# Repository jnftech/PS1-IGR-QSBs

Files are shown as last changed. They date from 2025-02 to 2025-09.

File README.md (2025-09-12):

## Playstation 1 In-Game Reset (IGR)
### QSBs for One-wire Controller-PCB installs
<br/>
<br/>

These boards are variations on [PyroESP's](https://github.com/pyroesp) Playstation 1 Reset Mod project.

The original project and code can be found at https://github.com/pyroesp/PlayStation-1-Reset-Mod

To simplify the goal of this project: When installed into a Playstation 1 system, it facilitates a reset of the system using a button combination on controller 1, by tapping into the controller signals and toggling the system reset line. This is useful for those that have ODEs installed, as you can reset back to the menu of the ODE from the controller instead of getting up to hold the reset button down.

Originally I had posted a variation that was more or less a shrink of their original PCB (which used a SOIC package for the microcontroller), but using the TSSOP version instead, to get the board as small as it could be for S&Gs and more of a "hardmode" install. This version of the project (while deprecated, unless you REALLY need to avoid installing to the controller PCB) is still hosted in the repository.

A while back (2022? Yes it has taken me that long to publish the final versions here) a member of the [Consolemods.org](https://www.consolemods.org) discord observed a variation on OSHpark that installed to the back of the controller PCB behind the player 1 port. However the project was not laid out correctly, thus the wrong (higher) voltage was applied to the microcontroller. This style of board is a "Quick Solder Board" (QSB), where the board is designed to sit on top of another PCB and solder directly to signal points (versus running a wire for each signal). Such a solution allows for a "one-wire" install of this project. All but one of the signals needed are available from the solder points of the controller ports themselves. The only wire that must be run is for the reset signal.
While these controller-PCB-mounted solutions were not uncommon at the time, the project on OSHpark appeared to be the only published gerbers for folks that prefer to fabricate their own PCBs.
I decided to revisit the project to produce a correctly-wired version, using my own consoles for measurement. Some earlier versions of the gerbers were posted to the discord for members to use. This respository has three variations depending on your soldering preferences.
  
Code, details of the solution, original PCB design, and instructions for programming and installation are available at [pyroesp's Github](https://github.com/pyroesp). Programming-ready hex file in the [releases section](https://github.com/pyroesp/PlayStation-1-Reset-Mod/releases)

</br></br></br>

### Controller-port (Port 1) install, SOIC Package (Normal difficulty) [(OSHpark)](https://oshpark.com/shared_projects/fwJTyytg)

<p align="center">
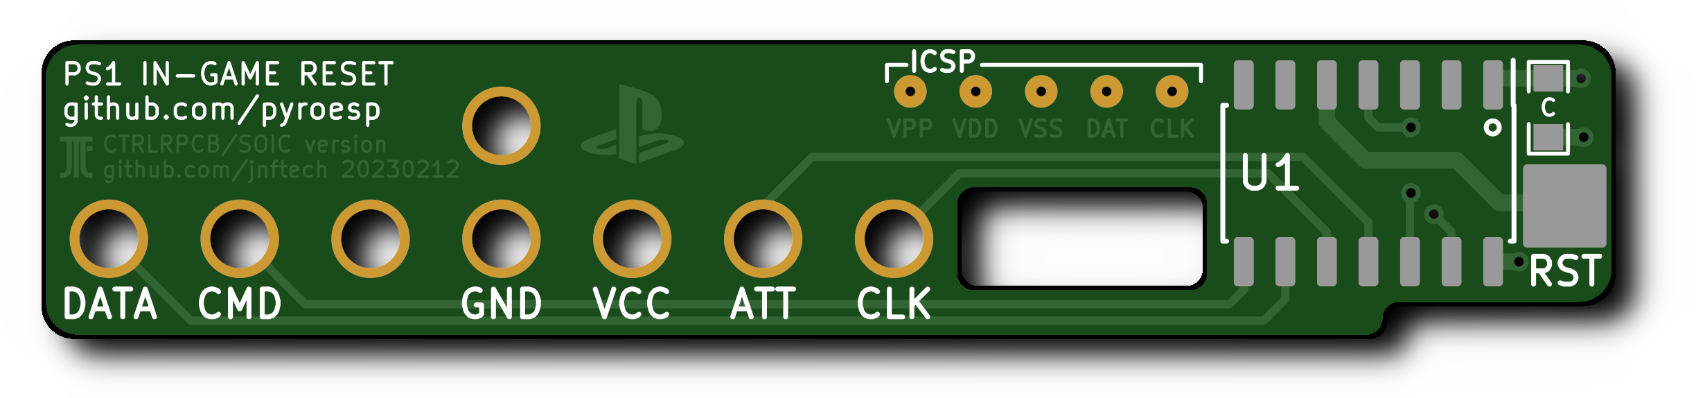
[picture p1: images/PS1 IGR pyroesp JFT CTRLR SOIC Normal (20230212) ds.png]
  
</p>
This variant more or less aimed to substitute the faulty one on OSHpark. Installs over the solder points for controller port 1 and uses the SOIC package of the microcontroller (MCU). This should be fairly easy to assemble for anyone with decent soldering skills.

</br></br>

### Controller-port (Port 1) install, TSSOP Package (Hard difficulty) [(OSHpark)](https://oshpark.com/shared_projects/G71d1amG)

<p align="center">
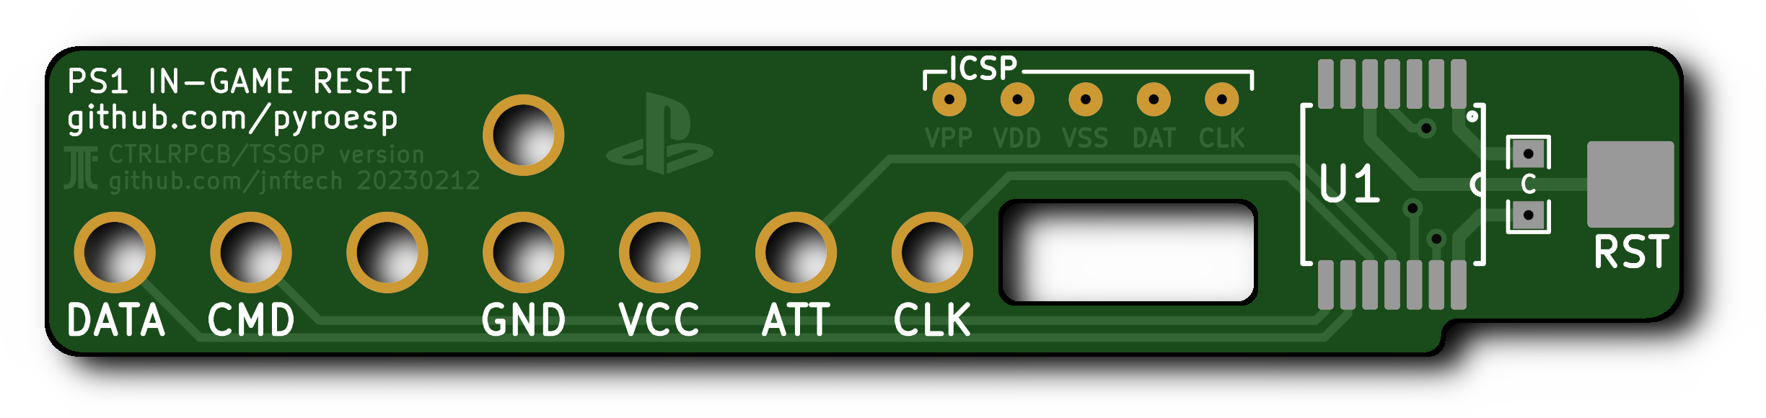
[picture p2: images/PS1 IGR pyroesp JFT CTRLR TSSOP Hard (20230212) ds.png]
  
</p>
This is almost identical to the above variant, and installs the exact same way. The only difference is the use of the TSSOP package for the MCU. This requires slightly tighter soldering skills.

</br></br>

### Controller-ribbon connector (Center of controller PCB) install, UQFN Package (Ultrahard difficulty) [(OSHpark)](https://oshpark.com/shared_projects/B2ZQAGCg)

<p align="center">
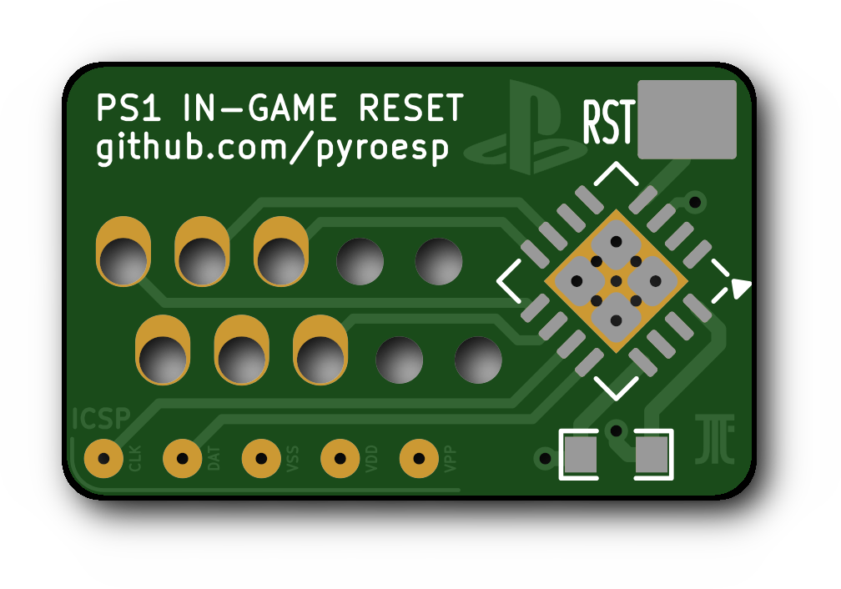
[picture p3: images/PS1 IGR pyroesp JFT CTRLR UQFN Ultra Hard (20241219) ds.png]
  
</p>
Staying in the same spirit as my original visit to the project, this board aims to be as small is it can be. I realized that another spot on the controller PCB contained all the same signals as the controller port: The connector for the ribbon cable that connects the controller assembly to the main system board. This PCB installs to the back of that connector instead of the controller port. Continuing with that same spirit, I figured go all out and use the UQFN package of the MCU - which is the smallest package it comes in. However this means this board is significantly more difficult to assemble by hand. Not impossible - I hand assembled the one installed in my main console - but takes very good soldering skills and tools. I imagine this is the smallest "one-wire" install of this solution available. All that said, the actual installation of the board into the console should not be much more difficult than the other two options.

</br></br>

### PSone install, Flex PCB, UQFN Package (Insane difficulty) BETA

<p align="center">
  
</p>
Info coming soon!
(Quick note for anyone that wants to try this one before I get around to filling in more details - this is intended to be a flex PCB to keep it as thin as possible (flex is 0.10mm - 0.12mm) and fit under the bottom RF shield. Put kapton tape over it after installation to keep it from touching the RF shield. I have tested this install on a PSone and it works as intended. Normal PCBs are likely too thick, though I have not tried this myself. Perhaps if the RF shield is cut or omitted a regular PCB would fit. i would still go as thin as possible, for example the 0.8mm on Oshpark. Though until I provide more detailed instructions, you will have to find the reset line on the PSone yourself, or look around online. I found a good spot from the PSone service manual.)

</br></br></br></br>

### BOM:

Only two components are needed:

**U1**<br/> Depending on which board you which to assemble, the part number for the MCU will differ slightly (only the last two characters of the part number matter in this case)
- SOIC: Microchip PIC16F18325-I/SL. [Digikey](https://www.digikey.com/en/products/detail/microchip-technology/PIC16F18325-I-SL/5323625)
- TSSOP: Microchip PIC16F18325-I/ST. [Digikey](https://www.digikey.com/en/products/detail/microchip-technology/PIC16F18325-I-ST/5323626)
- UQFN: Microchip PIC16F18325-I/JQ. [Digikey](https://www.digikey.com/en/products/detail/microchip-technology/PIC16F18325-I-JQ/5639473)

**C1**:<br/>You really don't need to be picky about this part. Any 100nf to 1000nf/1uf 0603-sized Ceramic capacitor rated at 16v or above will work. <br />
    Examples:<br />
        [Samsung CL10B104KB8NNNL](https://www.digikey.com/en/products/detail/samsung-electro-mechanics/CL10B104KB8NNNL/3894274)<br />
        [Murata GCJ188R71E104KA12D](https://www.digikey.com/en/products/detail/murata-electronics/GCJ188R71E104KA12D/7363221)

### Installation Notes:
- To completely remove the chance of shorts between the IGR board and any shielding it may come in contact with, place a piece of electrical tape over the board once installed, OR place electrical tape over the sheilding area it may come in contact with. I will add a photo of this at some point.

### Fabrication Notes:
- These boards benefit from being as thin as possible, due to being positioned between the controller PCB and the metal shielding between it and the rest of the casing. The default 1.6mm PCB thinckness may be a little tight, so it's recommended to go with 0.8mm thickness. If using OSHpark, an 0.8mm width option is available at checkout. Other fabs should have a similar thickness option, even thinner in some cases.
- The text in the bottom copper layer *may* cause some fabs to complain about the size of the text. OSHpark doesnt have an issue (they seem to fab whatever you throw at them, regardless if it comes out well in the final product), but I have experienced cases in the past where JLCPCB will remove any text from the board that they deem too small.
- There are other variants of the MCU you can use, depending on whether you have trouble sourcing the above (I did when I built my prototypes) but they may be a few cents more expensive as they have extra features or tolerances. In this project, they will all function identically:
  - The "I/" in the part number can be swapped with the "E/" variant. The latter is just "Extended Tempurature range"
  - This project uses the PIC16F18325 MCU, however the the PIC16F18**326** can also be used. It's the exact same MCU with a little bit more memory and storage. Same HEX file can be used to program either. The board I installed in my main console uses the PIC16F18326-E/JQ part. While the size of the code is fairly small, the next MCU down in the list (324) CANNOT be used as it lacks the dual SPI capability of the 325 and 326 (which this project requires).
- You will of course need a programmer to flash the code to the microcontroller, such as a PICkit3. This can be done in several ways:
  - The ICSP pads on board by soldering some temporary wiring to connect it to the programmer.
  - The ICSP pads by using a 2mm pitch pogo-pin PCB clamp such as this one on [Aliexpress](https://www.aliexpress.com/i/3256806664884457.html)
  - An alternative would be a DIP socket adapter ([an example of such on Aliexpress](https://www.aliexpress.com/item/32868905130.html)) to house the chip for programming before it is soldered to the board.

### Other Notes:
- These have not been designed with the PSone in mind, and are only tested on the original "phat" models. While the PSones have no good ODE option yet (where this mod is most useful), I have a variation in beta that I will be testing in the next few weeks.

### Tools used for this project:
- Tracespace View (SVG conversions of gerbers for the above images) https://tracespace.io/view/
- KiCad 8.0.6 https://www.kicad.org/
- GIMP for some of the image edits.
- Inkscape for some vector image edits.

### To-do
- Post more detailed installation instructions
- Post or link to reset line points for various motherboard revisions.

### License:
This derivative work maintains the same source license as the original board and project:  
Attribution-ShareAlike 4.0 International. See license file for more info

<br/><br/><br/><br/>
<p align="center">
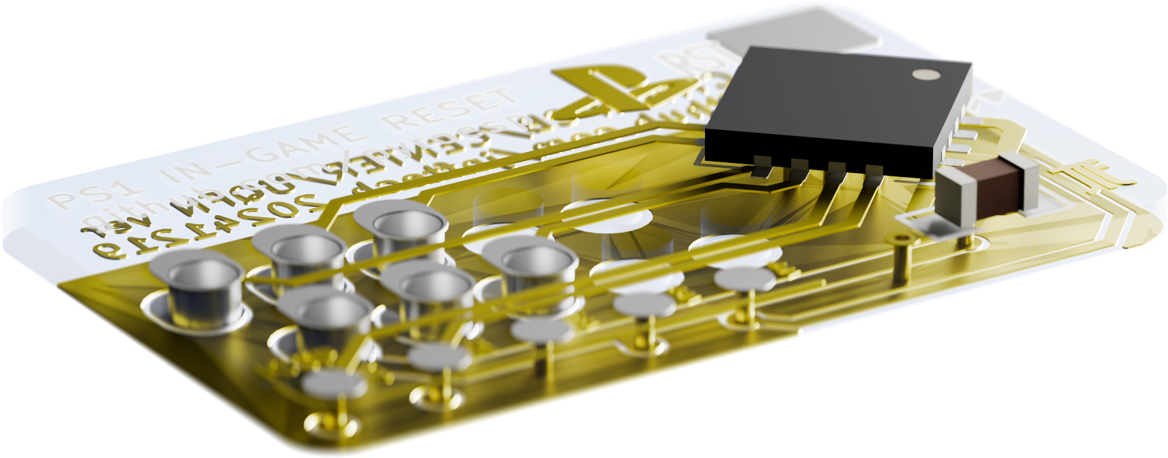
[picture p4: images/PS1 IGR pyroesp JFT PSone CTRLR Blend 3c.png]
  
</p><p align="center">
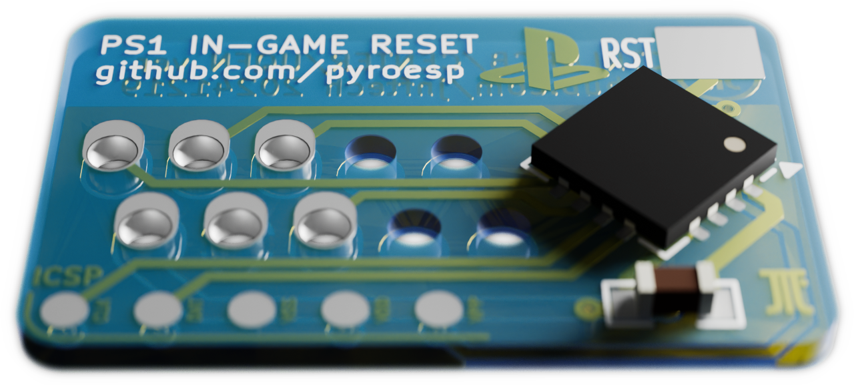
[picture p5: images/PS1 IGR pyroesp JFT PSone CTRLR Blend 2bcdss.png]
  
</p>
<br/><br/>

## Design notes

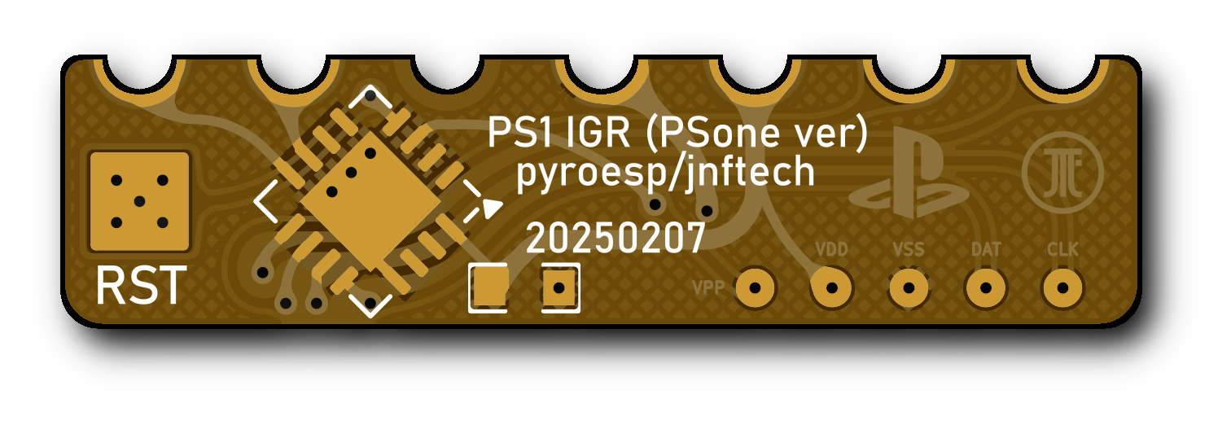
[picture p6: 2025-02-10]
images/PS1 IGR pyroesp JFT PSone UQFN (20250207) top flex ds.png

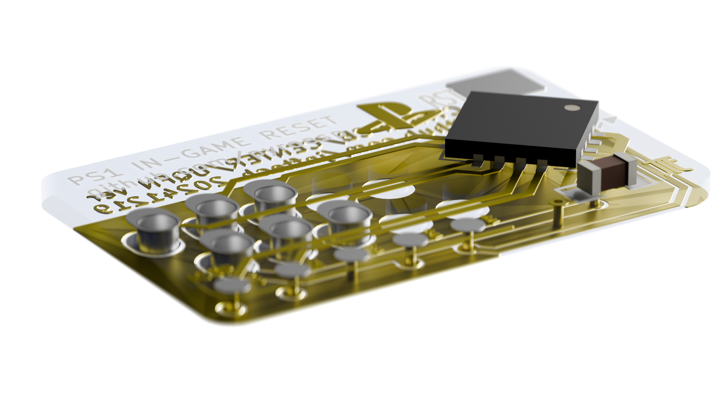
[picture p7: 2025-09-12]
images/PS1 IGR pyroesp JFT PSone CTRLR Blend 3.png

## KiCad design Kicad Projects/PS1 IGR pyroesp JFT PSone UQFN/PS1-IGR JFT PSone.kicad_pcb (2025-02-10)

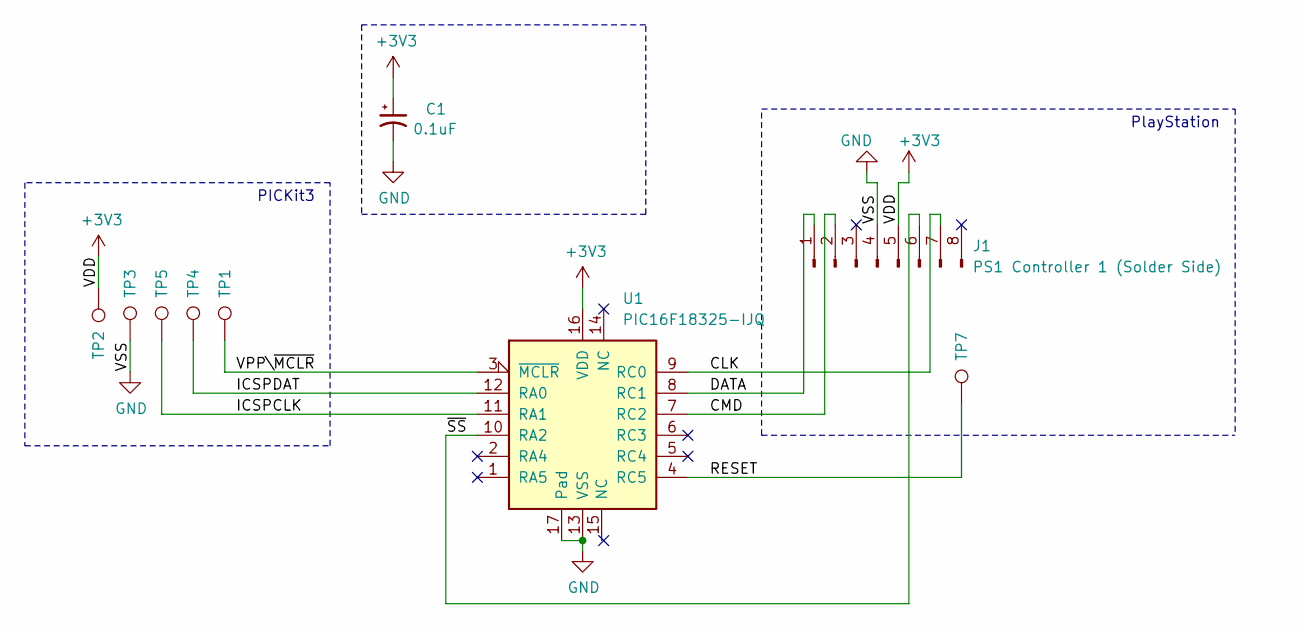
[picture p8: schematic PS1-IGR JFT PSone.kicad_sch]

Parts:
C1: 0.1uF; R_0603_0.8mm
J1: PS1 Controller 1 (Solder Side); PS1ControllerPort_SolderSide_1gnd0hv
TP1: VPP; TestPoint_Pad_NoSilk_D1.0mm
TP2: VDD; TestPoint_Pad_NoSilk_D1.0mm
TP3: VSS; TestPoint_Pad_NoSilk_D1.0mm
TP4: DAT; TestPoint_Pad_NoSilk_D1.0mm
TP5: CLK; TestPoint_Pad_NoSilk_D1.0mm
TP7: RST; Wirepad-2.54mm
U1: PIC16F18325-IJQ; UQFN-16-1EP_4x4mm_P0.65mm_EP2.6x2.6mm

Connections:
+3V3: C1.1, J1.5, TP2.1, U1.16 (VDD)
/CLK: J1.7, U1.9 (RC0)
/CMD: J1.2, U1.7 (RC2)
/DATA: J1.1, U1.8 (RC1)
/ICSPCLK: TP5.1, U1.11 (RA1)
/ICSPDAT: TP4.1, U1.12 (RA0)
/RESET: TP7.1, U1.4 (RC5)
/VPP\~MCLR: TP1.1, U1.3 (~MCLR)
/~SS: J1.6, U1.10 (RA2)
GND: C1.2, J1.4, TP3.1, U1.13 (VSS), U1.17 (Pad)

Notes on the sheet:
PICKit3
PlayStation

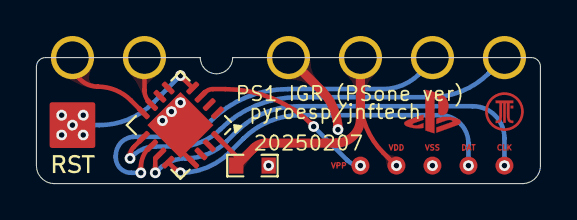
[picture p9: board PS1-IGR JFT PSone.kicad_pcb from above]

Board: 2 copper layers, 28.0 x 7.0 mm, 9 parts (0 on the bottom side), 10 nets.
